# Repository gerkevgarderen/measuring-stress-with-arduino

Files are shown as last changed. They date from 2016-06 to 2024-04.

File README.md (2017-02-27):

# Measuring Stress with Arduino
_Using a Heart Beat Sensor to measure stress levels in the human body_

This project is designed to measure heartbeat with an Arduino with heart beat sensor module.
The Arduino then does a Fast Hartley Transform (FFH, alternative for Fourier) transform to generate the Heart-Rate-Variability (HRV) values.
Based on these values, a relatively accurate indication of the stress levels can be found.

**Background on measuring stress through HRV**

>Thayer, J. F., Åhs, F., Fredrikson, M., Sollers III, J. J., & Wager, T. D. (2012). A meta-analysis of heart rate variability and neuroimaging studies: Implications for heart rate variability as a marker of stress and health. _Neuroscience & Biobehavioral Reviews, 36_(2), 747-756. doi:10.1016/j.neubiorev.2011.11.009

**Background on FFH (the calculation that is used)**

>Piccinin, F., & Department of Defence, South Australia. (1967). _THE FAST HARTLEY TRANSFORM AS AN ALTERNATIVE TO THE FAST FOURIER TRANSFORM _(Technical Memorandum). Retrieved from http://www.dtic.mil/dtic/tr/fulltext/u2/a212493.pdf

This edited and extended version of code was written by Gerke van Garderen, https://gerkevangarderen.nl/.
It is written as an extension of existing heart rate sensor code, to add stress sensing through monitoring of Heart Rate Variability (HRV).

**Heart rate sensor code is copied from: Pulse Sensor Amped 1.4** by Joel Murphy and Yury Gitman of http://www.pulsesensor.com.
For the original Pulse Sensor Amped code and license of said code, please see: 
https://github.com/WorldFamousElectronics/PulseSensor_Amped_Arduino/blob/master/

Change made:
Added the HRV-calculations and display in the design, as well as shortening of the original Heart Rate Sensor code to preserve resources on the Arduino.

**Note: Code is based on Arduino Pro Mini. If you use a different arduino, some changes to port numbers need to be made.
Also, because this code makes use of Timer2, pins 3 and 11 lose PWM-functionality.**

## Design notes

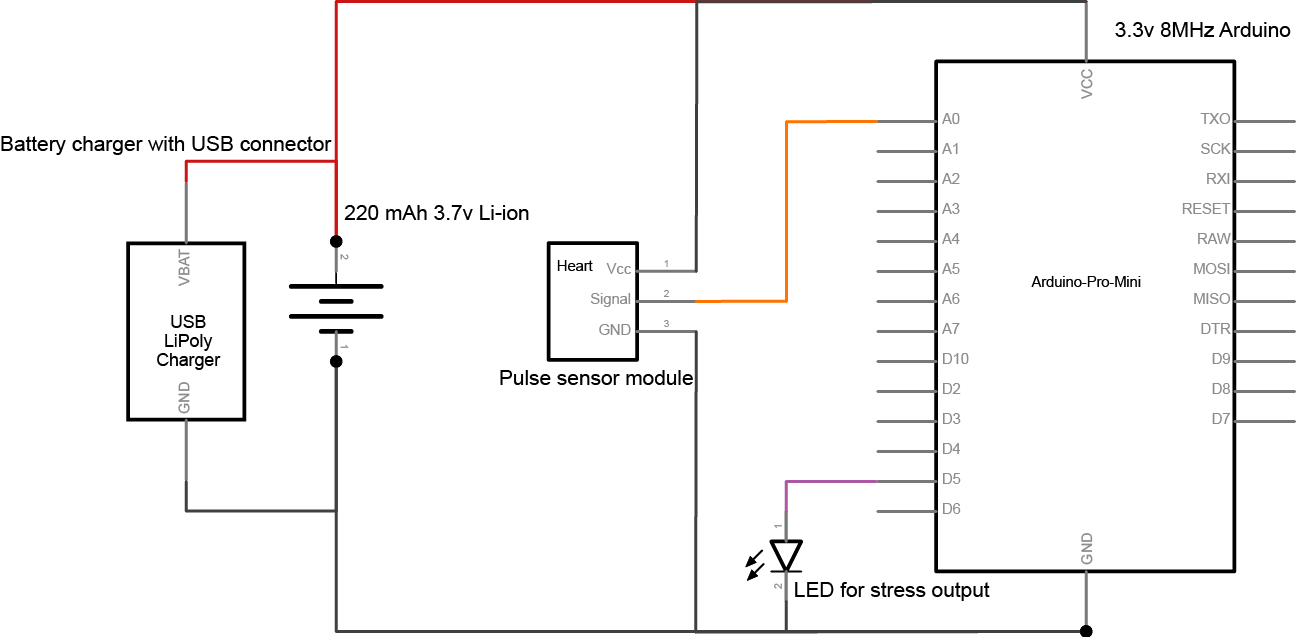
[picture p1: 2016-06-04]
Schematics Pondus.png

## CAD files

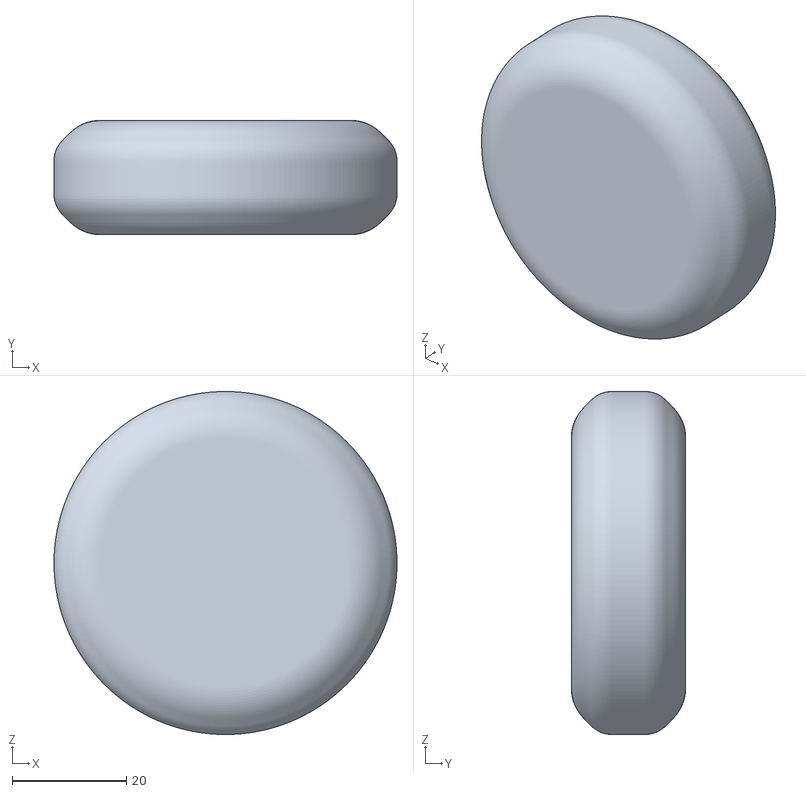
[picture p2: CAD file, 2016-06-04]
Main hull_final.stl
60.0 x 20.0 x 60.0

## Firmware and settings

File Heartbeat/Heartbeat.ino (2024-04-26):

/*  Heart sensor code is based on: Pulse Sensor Amped 1.4 by Joel Murphy and Yury Gitman of http://www.pulsesensor.com
 *  For the original Pulse Sensor Amped code and license of said code, please see: https://github.com/WorldFamousElectronics/PulseSensor_Amped_Arduino/blob/master/LICENSE
 */

/*
 * This edited and extended version of code was written by Gerke van Garderen, https://gerkevangarderen.nl/
 * It was written as an extension of beformentioned code, to add stress sensing through monitoring of Heart Rate Variability (HRV)
 * 
 * Note: because the sensor code makes use of Timer2, pins 3 and 11 lose PWM-functionality.
 */

#define LOG_OUT 1 // use the log output function
#define FHT_N 32  // Set number of data points the FHT will use

#include <FHT.h>  // include the library for Fourier transform

#define vibrationPin 5
boolean vibing = true; //checks whether vibration is currently on
boolean silence = false;
long vibeTimeSet = 500;
long vibeTimer = 0;

float HF=0;
float LF=0;
float LFHF,LFHFOld;


//  Variables
int pulsePin = A0;                  // Pulse Sensor purple wire connected to analog pin 0
int blinkPin = 13;                  // pin to blink led at each beat

// Volatile Variables, used in the interrupt service routine!
volatile int BPM;                   // int that holds raw Analog in 0. updated every 2mS
volatile int Signal;                // holds the incoming raw data
volatile int IBI = 600;             // int that holds the time interval between beats! Must be seeded! 
volatile boolean Pulse = false;     // "True" when User's live heartbeat is detected. "False" when not a "live beat". 
volatile boolean QS = false;        // becomes true when Arduoino finds a beat.

int data[32];
int dataCount = 0;
boolean once = false;

void setup(){
  pinMode(blinkPin,OUTPUT);         // pin that will blink to your heartbeat!

  Serial.begin(115200);             // we agree to talk fast!
  interruptSetup();                 // sets up to read Pulse Sensor signal every 2mS 
}


void loop(){
  if (QS == true){                      // A Heartbeat Was Found, BPM and IBI have been Determined. Quantified Self "QS" is set to true when arduino finds a heartbeat
        serialOutputWhenBeatHappens();  // A Beat Happened, Output that to serial. 
        Fourier();                      // Run the Fourier code to calculate HF/LF    
        QS = false;                     // reset the Quantified Self flag for next time    
  }
  delay(10);                            //  take a break
}

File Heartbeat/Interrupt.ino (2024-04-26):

// Interrupt code (mostly originating from Pulse Sensor Amped 1.4, small edits by Gerke)

// Only used to calculate BPM: volatile int rate[10];                      // array to hold last ten IBI values
volatile unsigned long sampleCounter = 0;   // used to determine pulse timing
volatile unsigned long lastBeatTime = 0;    // used to find IBI
volatile int P = 512;                       // used to find peak in pulse wave, seeded
volatile int T = 512;                       // used to find trough in pulse wave, seeded
volatile int thresh = 525;                  // used to find instant moment of heart beat, seeded
volatile int amp = 100;                     // used to hold amplitude of pulse waveform, seeded
volatile boolean firstBeat = true;          // used to seed rate array so we startup with reasonable BPM
volatile boolean secondBeat = false;        // used to seed rate array so we startup with reasonable BPM


void interruptSetup(){     
  // Initializes Timer2 to throw an interrupt every 2mS.
  TCCR2A = 0x02;     // DISABLE PWM ON DIGITAL PINS 3 AND 11, AND GO INTO CTC MODE
  TCCR2B = 0x05;     // DON'T FORCE COMPARE, 128 PRESCALER 
  OCR2A = 0X7C;      // SET THE TOP OF THE COUNT TO 124 FOR 500Hz SAMPLE RATE
  TIMSK2 = 0x02;     // ENABLE INTERRUPT ON MATCH BETWEEN TIMER2 AND OCR2A
  sei();             // MAKE SURE GLOBAL INTERRUPTS ARE ENABLED      
  TIMSK0 = 0;
} 


// THIS IS THE TIMER 2 INTERRUPT SERVICE ROUTINE. 
// Timer 2 makes sure that we take a reading every 2 miliseconds
ISR(TIMER2_COMPA_vect){                         // triggered when Timer2 counts to 124
  cli();                                      // disable interrupts while we do this
  Signal = analogRead(pulsePin);              // read the Pulse Sensor 
  sampleCounter += 2;                         // keep track of the time in mS with this variable
  int N = sampleCounter - lastBeatTime;       // monitor the time since the last beat to avoid noise
 
  // Subtract the two millisecond interval from the output time
  vibeTimer = max(0,vibeTimer-2);
  
  // Optionally some debugging prints
  // Serial.println(vibeTimer);
  // Serial.println(vibeTimeSet);
  // Serial.println(vibeTime1);

  /* Here is where we provide the feedback of the measured stress;
   *  with a vibration motor in this case.
   * 
   * The code works as follows:
   *   1. Turn on vibration motor for 200millis
   *   2. Turn off vibration motor for the duration of vibeTimeSet - based on the LF/HF ratio calculated in Fourier.ino
   *   3. Repeat
   */

  // If motor is on and timer has reached 0:
  if (vibing && vibeTimer == 0){

    // Set output to 0
    analogWrite(vibrationPin,0);

    // Update status
    vibing = false;
    silence = true;
    
    // Set new timer with duration vibeTimeSet
    // The motor will stay off for this duration
    vibeTimer = vibeTimeSet;

  } else if (silence && vibeTimer == 0){
    // Stop the silence in next cycle
    silence = false;
  } else if (!silence && !vibing ){
    vibing = true;
    // Set new timer
    vibeTimer = 200;

    // Turn vibration feedback motor on
    analogWrite(vibrationPin,150);
  }

  // === End of vibration feedback // Start of heart rate sensor measurements ===

  // Find the peak and trough of the pulse wave
  if(Signal < thresh && N > (IBI/5)*3){       // avoid dichrotic noise by waiting 3/5 of last IBI
    if (Signal < T){                        // T is the trough
      T = Signal;                         // keep track of lowest point in pulse wave 
    }
  }

  if(Signal > thresh && Signal > P){          // thresh condition helps avoid noise
    P = Signal;                             // P is the peak
  }                                        // keep track of highest point in pulse wave

  //  NOW IT'S TIME TO LOOK FOR THE HEART BEAT
  // signal surges up in value every time there is a pulse
  if (N > 250){                                   // avoid high frequency noise
    if ( (Signal > thresh) && (Pulse == false) && (N > (IBI/5)*3) ){        
      Pulse = true;                               // set the Pulse flag when we think there is a pulse
      digitalWrite(blinkPin,HIGH);                // turn on pin 13 LED
      IBI = sampleCounter - lastBeatTime;         // measure time between beats in mS
      lastBeatTime = sampleCounter;               // keep track of time for next pulse

      /* Code used for BPM, we only need IBI
       * if(secondBeat){                        // if this is the second beat, if secondBeat == TRUE
       *   secondBeat = false;                  // clear secondBeat flag
       *   for(int i=0; i<=9; i++){             // seed the running total to get a realisitic BPM at startup
       *     rate[i] = IBI;                      
       *   }
       * }
       */

      if(firstBeat){                         // if it's the first time we found a beat, if firstBeat == TRUE
        firstBeat = false;                   // clear firstBeat flag
        secondBeat = true;                   // set the second beat flag
        sei();                               // enable interrupts again
        return;                              // IBI value is unreliable so discard it
      }   

      /* Code used for BPM, we only need IBI 
       * // keep a running total of the last 10 IBI values
       * word runningTotal = 0;                  // clear the runningTotal variable    
       *
       * for(int i=0; i<=8; i++){                // shift data in the rate array
       *   rate[i] = rate[i+1];                  // and drop the oldest IBI value 
       *   runningTotal += rate[i];              // add up the 9 oldest IBI values
       * }
       *
       *
       * rate[9] = IBI;                          // add the latest IBI to the rate array
       * runningTotal += rate[9];                // add the latest IBI to runningTotal
       * runningTotal /= 10;                     // average the last 10 IBI values 
       * BPM = 60000/runningTotal;               // how many beats can fit into a minute? that's BPM!
       */
 
      QS = true;                              // set Quantified Self flag 
      // QS FLAG IS NOT CLEARED INSIDE THIS ISR
    }                       
  }

  if (Signal < thresh && Pulse == true){   // when the values are going down, the beat is over
    digitalWrite(blinkPin,LOW);            // turn off pin 13 LED
    Pulse = false;                         // reset the Pulse flag so we can do it again
    amp = P - T;                           // get amplitude of the pulse wave
    thresh = amp/2 + T;                    // set thresh at 50% of the amplitude
    P = thresh;                            // reset these for next time
    T = thresh;
  }
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

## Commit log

2016-06-01 Main function for Arduino code
2016-06-01 Arduino code
    Removed Vcc for sensor from output pin. Sensor must now be directly
    powered from main power source.
    Added feedback through PWM pin 5, for the biofeedback of LF/HF.
2016-06-01 Revert "Arduino code"
    This reverts commit 85c823fefec278b1ebdb05d5f174d670d74a4b77.
    [Fourier.ino, Heartbeat.ino, Interrupt.ino]
2016-06-01 Arduino update: added biofeedback; change power source sensor
    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
2016-06-01 3D file of the case used in the design
    [Main hull.stl]
2016-06-04 Small error correction: larger opening for sensor
    [Main hull.stl, Main hull_final.stl]
2016-06-04 First draft of current hardware setup
2016-06-04 Schematics used in the final design iteration
    [Schematics Pondus.fzz]
2024-04-26 Correct the shift direction
    [Fourier.ino]
